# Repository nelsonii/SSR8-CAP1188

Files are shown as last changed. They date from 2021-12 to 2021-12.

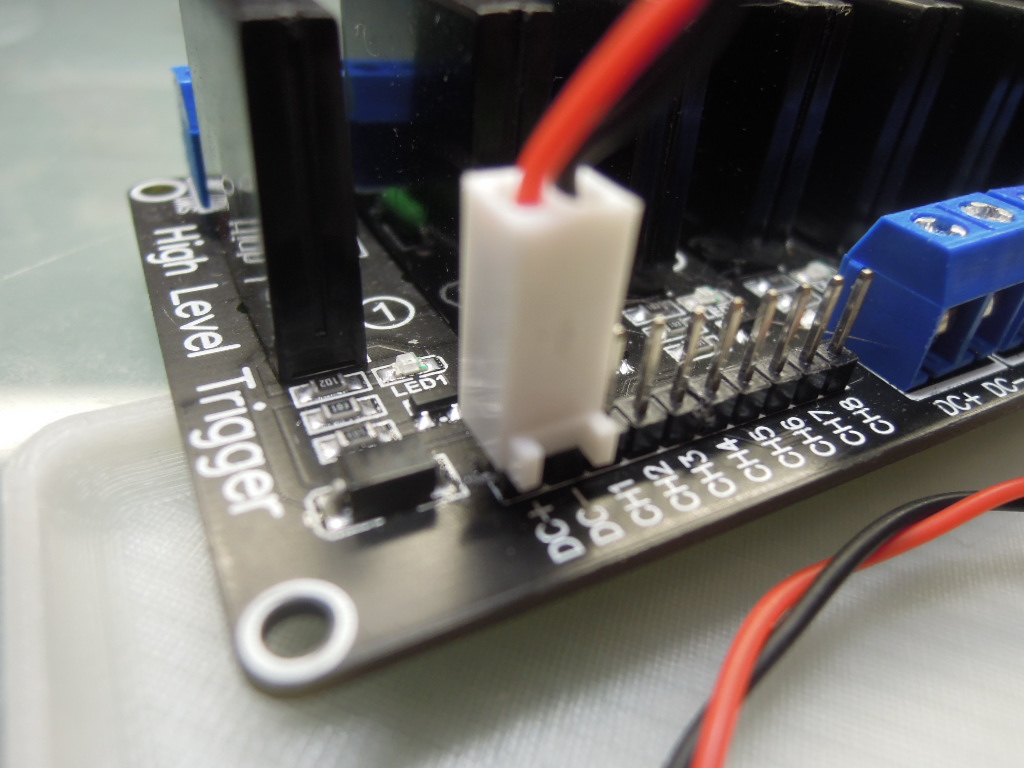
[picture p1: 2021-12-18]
2021-12-18/DSCN8659.JPG

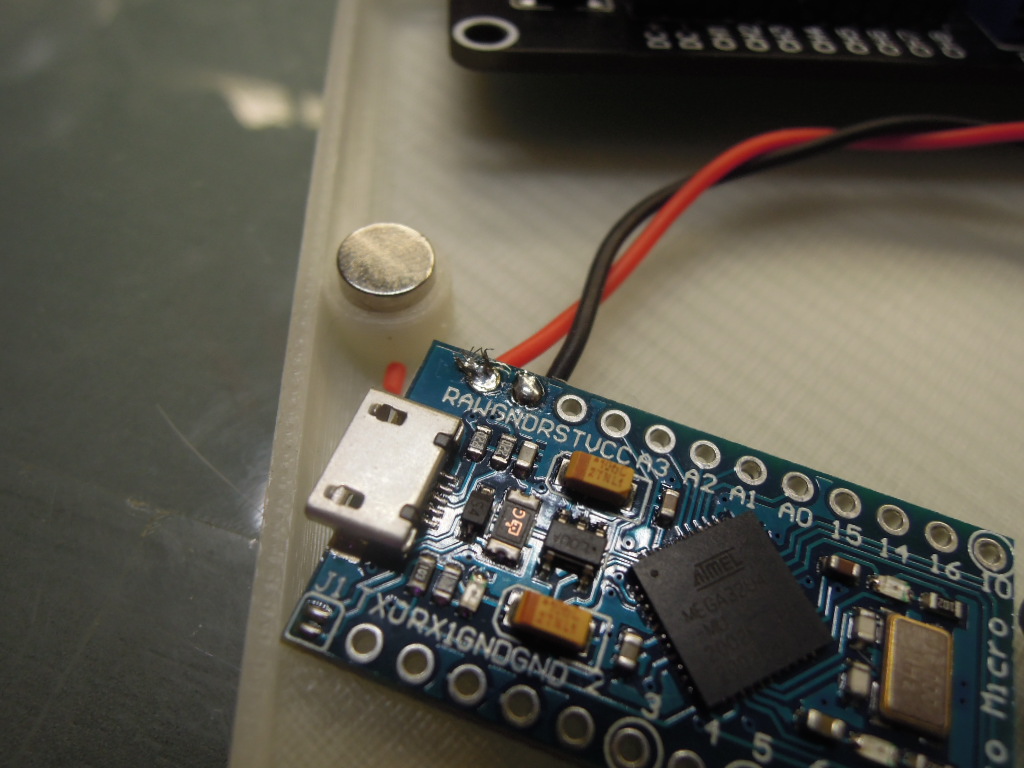
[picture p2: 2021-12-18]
2021-12-18/DSCN8655.JPG

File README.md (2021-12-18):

# SSR8-CAP1188
Controlling Solid Stay Relays with Capacitive Sensor (CAP1188) Board

BoM:

(1) AITRIP 2PCS 8 Channel 5V Solid State Relay Module Board High Level Trigger (or similar)
(1) Adafruit CAP1188 breakout board (or similar)
(1) USB To DIP Adapter 5pin Female Connector B Type PCB Converter (or similar -- or USB C, if you prefer)
(1) USB Type A Female Socket Breakout Board 2.54mm Pitch Adapter Connector DIP (optional -- for pass-thru power)
(1) Arduino Pro Mico or similar. Nano will work. Should also work with QT PY or similar.
(1) G/KF128 8 Pin 2.54mm Pitch PCB Screw Terminal Block Connector 150V 6A PCB Mount Screw Terminal Block Connector
(x) Assorted wire and connectors, solder, tools.

---

Power (VCC and GND) bussed through USB connectors, CAP, Arduino, and SSR -- common 5V power from USB in.
Power the device through the external supply connection, not the program port. (Prevents overload of Arduino.)

CAP1188 board LED outs go to SSR inputs.
CAP1188 board I2C to MCU.
CAP1188 board RST to MCU digital pin (any--define in code).

---

The two front-facing USB female connectors are for power in (from a wall wart) and power out (so you can daisy-chain).

I used a tiny (2.54mm pitch) screw terminal block for connecting the CAP inputs. You may choose a different connector.

Outbound connectors are already on the relay board.

---

If you print the enclosure, you can start (or only do) the bottom. That has all the mounting points. The top takes 2.5 hrs to print, so save that for when all is working. I'm using 6x2 magnets (4) to attach the top, as it will be removed often. 2.5x4mm screws for most boards, except 2.0mm for CAP1188. Invert the top Y 180 in slicer.

---

Caution: The relay board isn't always the greatest. I've found some of the screw terminal blocks to be broken, or messed up. You may need to re-solder them. Also, I found the Input Terminal blocks to be too big/sloppy for my wiring from the CAP1188. So, I used Molex connectors and the pin header found on the SSR board for the inputs. The extra benefit of this is that those blocks are free for other prototyping uses.

---

Some devices act a little weird on the output side. The little "singing baby shark" toy works perfectly. A cheap LED "snowglobe" can be intermittant. This may be a wiring problem in the device -- I'm still debugging.

---

You can use the default test code provided by Adafruit. You MUST add this line to setup: 
  //reverse led polarity
  //on-board led will go off, SSR will be triggered on
  cap.writeRegister(0x73, 0xFF);

---

WARNING: On startup, all outputs will go ACTIVE for a second, as the board boots. Do not use this in situations where this would cause a problem! I'm working on a better version which will "fail/start" off in all conditions. This will likely involve connecting the SSR directly to the Arduino Digital Outs, instead of piggy-backing on the CAP1188.

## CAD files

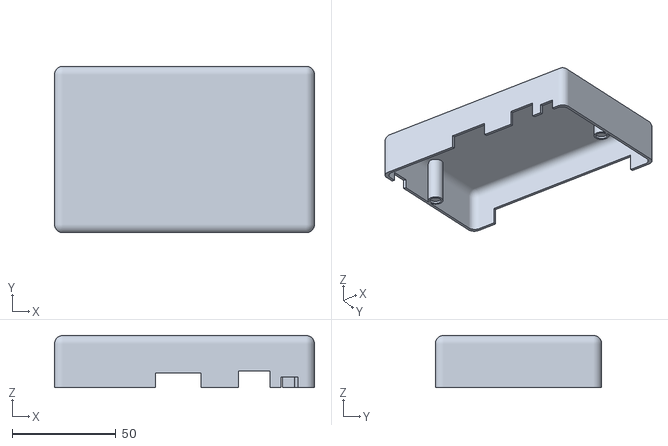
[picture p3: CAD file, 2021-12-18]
SSREnclosure/SSREnclosure_x8_v1L_TOP.stl
125.0 x 80.0 x 25.0

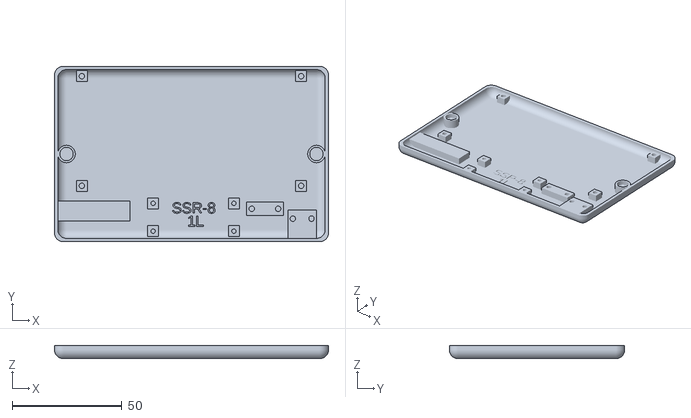
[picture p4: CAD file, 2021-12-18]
SSREnclosure/SSREnclosure_x8_v1L_BOT.stl
125.0 x 80.0 x 6.01

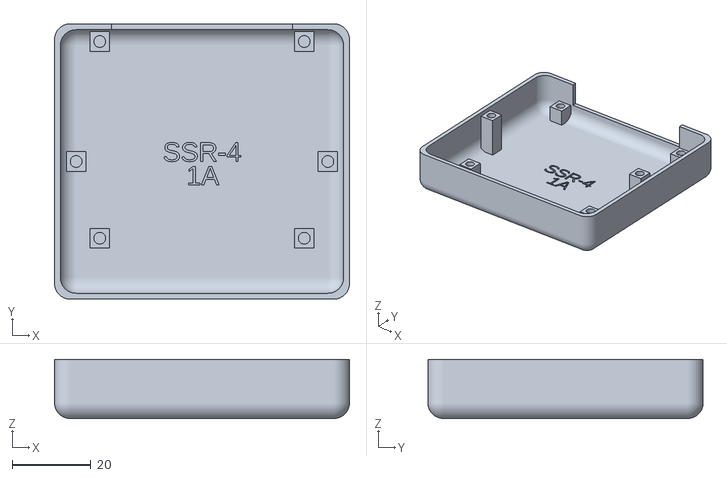
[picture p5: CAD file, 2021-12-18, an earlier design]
SSREnclosure/OLD/SSREnclosure_v1A.stl
75.0 x 70.0 x 15.0

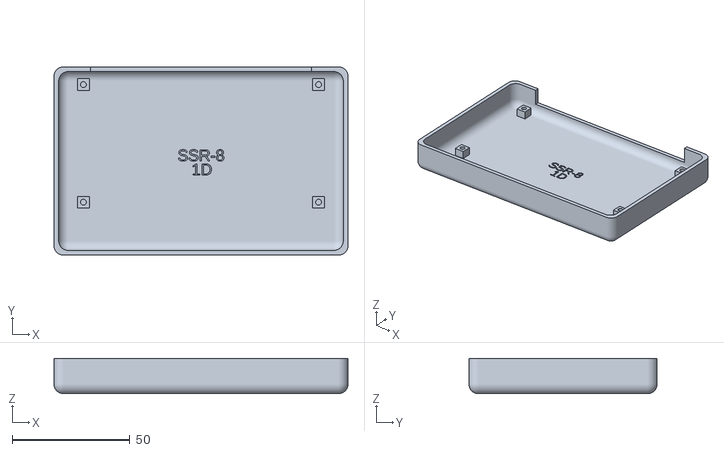
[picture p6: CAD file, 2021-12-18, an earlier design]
SSREnclosure/OLD/SSREnclosure_x8_v1D.stl
125.0 x 80.0 x 15.0

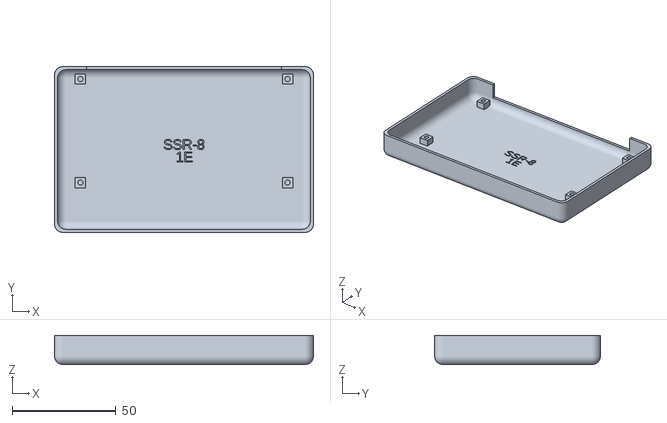
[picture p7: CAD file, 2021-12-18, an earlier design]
SSREnclosure/OLD/SSREnclosure_x8_v1E.stl
125.0 x 80.0 x 14.0

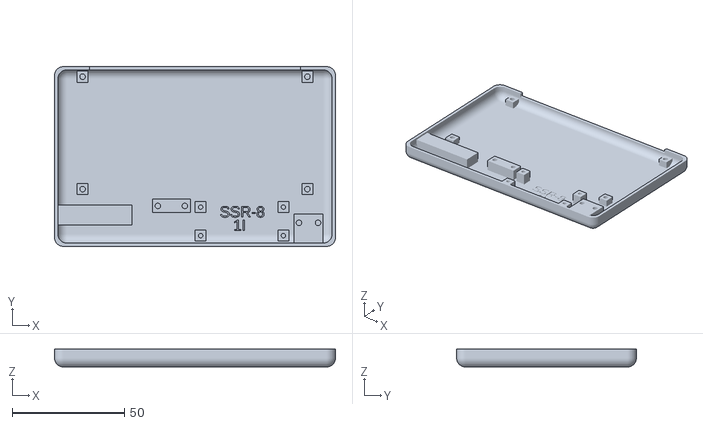
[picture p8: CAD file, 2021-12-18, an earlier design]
SSREnclosure/OLD/SSREnclosure_x8_v1I.stl
125.0 x 80.0 x 8.01

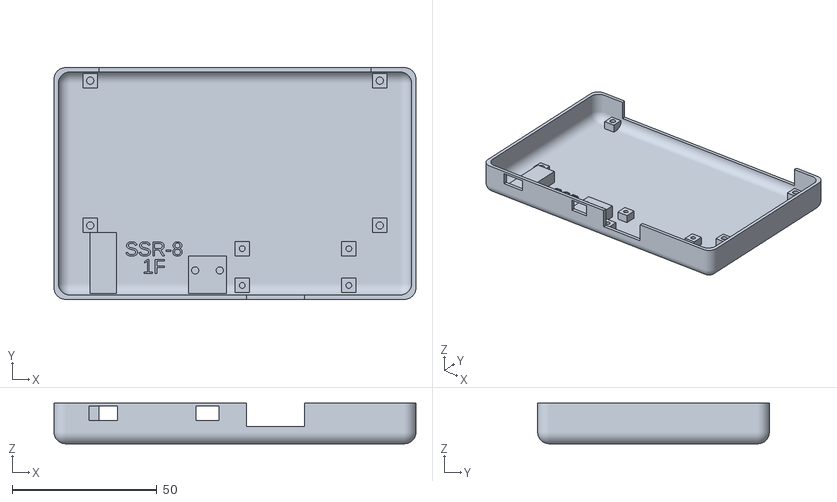
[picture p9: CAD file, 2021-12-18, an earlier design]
SSREnclosure/OLD/SSREnclosure_x8_v1F.stl
125.0 x 80.0 x 14.0

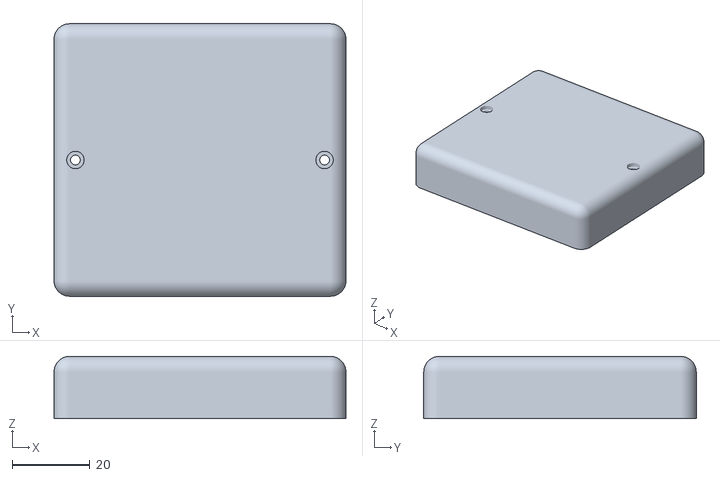
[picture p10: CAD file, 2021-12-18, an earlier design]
SSREnclosure/OLD/SSREnclosure_v1C_TOP.stl
75.0 x 70.0 x 16.0

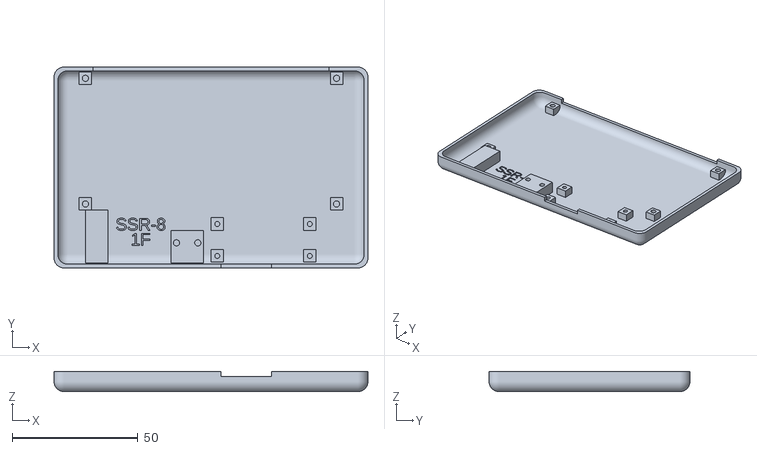
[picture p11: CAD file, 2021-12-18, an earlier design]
SSREnclosure/OLD/SSREnclosure_x8_v1F_BOT.stl
125.0 x 80.0 x 8.01

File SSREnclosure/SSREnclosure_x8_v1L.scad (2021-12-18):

fileDescription = "Solid State Relay Enclosure (x8)";
fileType = "SSR-8";
fileVersion = "1L";

// Designed to fit an 8 SSR board, QT PY 
// or Arduino Micro Pro (Leo) mcus
// and CAP1188 Capacitive sensor board.
// Includes breakout boards for USB Micro In and USB A Out

//The Belfry OpenSCAD Library
//https://github.com/revarbat/BOSL
include <BOSL/constants.scad>
use <BOSL/shapes.scad>

// using "high level trigger" so as to fail to "off"
// 8 solid state relay dimensions
// x=105, y=55, z=25
// z includes pins extending from PCB bottom
// mounting hole distance: x=100, y=50
// output jacks x=94, z=10

caseWidthX = 125;
caseDepthY = 80;
caseHeightZ = 32;
wallThickness = 3;

relayBoardMountX = 100;
relayBoardMountY = 50;
relayBoardOutputWidth = 94;

outputZ = 4; // height above Z-zero where connector is (works for both relay & cap board).

capBoardMountX = 36.83;
capBoardMountY = 12.7;
capBoardInputWidth = 22;
capBoardScrewDiameter = 2; //M2* for CAP1188 board

//This model supports two MCU board types. 
//QTPY = Adafruit QT PY board (USB-C)
//ARPO = Arduino Pro Micro (aka Leonardo)
//You can use other boards, but will need to do your own standoffs.
mcuType = "ARPO"; // either: QTPY or ARPO

mcuQtPyX = 21;
mcuQtPyY = 18;
mcuArPoX = 33;
mcuArPoY = 18;

standoffSize = 5; // size of standoffs/mounts for boards and case enclosure
overlap = 1; // overlap ensures that subtractions go beyond the edges


// M2.5*4 for relay board
// M2.5*4 for USB boards
// M2.0*  for CAP board -- requires M2.0 screws!
mountingScrewDiameter = 2.5; // M2.5
mountingScrewHeadDiameter = 4.5; // M2.5
mountingScrewHeadHeight = 2.7; // M2.5 

//case closure magnets (instead of screws)
magStandoffSize=8;
magDiameter=6.1;
magHeight=2.2;

emboss = true;
  
$fn=60; //circle smoothness
  
difference(){
  union() {
    difference(){
      //base
      //rounded cuboid is from the BOSL library
      //I'm using p1 setting to zero bottom (z). X/Y are centered on 0,0,0
      color("steelblue")
      cuboid([caseWidthX,caseDepthY,caseHeightZ], fillet=4, 
       p1=[-(caseWidthX/2), -(caseDepthY/2), 0]);
      //subtract out the inner cuboid
      cuboid([caseWidthX-wallThickness,caseDepthY-wallThickness,caseHeightZ-wallThickness], fillet=4, 
       p1=[-((caseWidthX-wallThickness)/2), -((caseDepthY-wallThickness)/2), (wallThickness/2)]);
      if (emboss) {
        //emboss version on inside case
        color("whitesmoke")
         translate([-9, -27, 1])
          linear_extrude(2)
           text(fileType, size=5);
        color("whitesmoke")
         translate([-2,-33, 1])
          linear_extrude(2)
           text(fileVersion, size=5);
      }//emboss
    }//difference (base)

    //relay board mounts
    color("khaki")
     translate([-(relayBoardMountX/2)-(standoffSize/2), (relayBoardMountY/2)+standoffSize+wallThickness, 1])
      cube([standoffSize,standoffSize,outputZ]);
    color("khaki")
     translate([+(relayBoardMountX/2)-(standoffSize/2), (relayBoardMountY/2)+standoffSize+wallThickness, 1])
      cube([standoffSize,standoffSize,outputZ]);
    color("khaki")
     translate([-(relayBoardMountX/2)-(standoffSize/2), -(relayBoardMountY/2)+standoffSize+wallThickness, 1])
      cube([standoffSize,standoffSize,outputZ]);
    color("khaki")
     translate([+(relayBoardMountX/2)-(standoffSize/2), -(relayBoardMountY/2)+standoffSize+wallThickness, 1])
      cube([standoffSize,standoffSize,outputZ]);
      
    //CAP1188 board mounts
    color("peachpuff")
     translate([-20+0, -30+standoffSize, 1])
      cube([standoffSize,standoffSize,outputZ]);
    color("peachpuff")
     translate([-20+capBoardMountX, -30+standoffSize, 1])
      cube([standoffSize,standoffSize,outputZ]);
    color("peachpuff")
     translate([-20+0, -30+standoffSize-capBoardMountY, 1])
      cube([standoffSize,standoffSize,outputZ]);
    color("peachpuff")
     translate([-20+capBoardMountX, -30+standoffSize-capBoardMountY, 1])
      cube([standoffSize,standoffSize,outputZ]);

    //Microcontroller board mount
    if (mcuType=="QTPY") {
      //MCU (ADAFRUIT QT PY) board mount
      color("hotpink")
       translate([-(caseWidthX/2)+(wallThickness/2), -(caseDepthY/2)+(wallThickness/2)+8, 1])
        cube([mcuQtPyX, mcuQtPyY/2, outputZ]);
    }
    if (mcuType=="ARPO") {
      //MCU (ARDUINO PRO MICRO) board mount
      color("deeppink")
       translate([-(caseWidthX/2)+(wallThickness/2), -(caseDepthY/2)+(wallThickness/2)+8, 1])
        cube([mcuArPoX, mcuArPoY/2, outputZ]);
    }
     
    //USB Micro breakout board mount (for power input)
    color("lime")
     translate([44, -(caseDepthY/2)+(wallThickness/2), 1])
      cube([13, 13, outputZ]);
      
    //Aux USB A output mount (for daisy chain of power to other devices)
    color("olive")
     translate([25, -28, 1])
      cube([17, 6, outputZ]);

    //case magnet mounts
    color("gold")
     translate([-57, 0, 1])
      cylinder(h=caseHeightZ-2, d=magStandoffSize);
    color("gold")
     translate([+57, 0, 1])
      cylinder(h=caseHeightZ-2, d=magStandoffSize);    
      
  }//union
  

  // Start of Difference stuff ************************************************************

  //Relay output connections
  color("coral")
   translate([-(relayBoardOutputWidth/2),(caseDepthY/2)-wallThickness, outputZ+2])
    cube([relayBoardOutputWidth, (wallThickness*2), 10]);

  //CAP input connections
  color("coral")
   translate([-20+6,-(caseDepthY/2)-wallThickness, outputZ+2])
    cube([capBoardInputWidth, (wallThickness*2), 8]);
  
  //MCU (PRG) connection (USB-C/Micro)
  color("coral")
   translate([-(caseWidthX/2)-(wallThickness/2), -(caseDepthY/2)+(wallThickness/2)+7.5, outputZ+2])
    cube([(wallThickness*2), 10, 6]);

  //Alt USB Micro power connection (in)
  color("coral")
     translate([46.50, -(caseDepthY/2)-wallThickness, outputZ+2])
      cube([8, (wallThickness*2), 6]);
    
  //Alt USA A power connection (out -- for daisy chain)
  color("coral")
     translate([26, -(caseDepthY/2)-wallThickness, outputZ+2])
      cube([15, (wallThickness*2), 9]);

  //screw holes for relay board mounts
  color("orangered")
   translate([-(relayBoardMountX/2), +(relayBoardMountY/2)+standoffSize+(standoffSize/2)+wallThickness, (wallThickness/2)])
    cylinder(h=outputZ, d=mountingScrewDiameter);
  color("orangered")
   translate([+(relayBoardMountX/2), +(relayBoardMountY/2)+standoffSize+(standoffSize/2)+wallThickness, (wallThickness/2)])
    cylinder(h=outputZ, d=mountingScrewDiameter); 
  color("orangered")
   translate([-(relayBoardMountX/2), -(relayBoardMountY/2)+standoffSize+(standoffSize/2)+wallThickness, (wallThickness/2)])
    cylinder(h=outputZ, d=mountingScrewDiameter);
  color("orangered")
   translate([+(relayBoardMountX/2), -(relayBoardMountY/2)+standoffSize+(standoffSize/2)+wallThickness, (wallThickness/2)])
    cylinder(h=outputZ, d=mountingScrewDiameter); 
    
  //screw holes for cap board mounts
  color("orangered")
   translate([-20+(standoffSize/2), -30+(standoffSize*1.5), (wallThickness/2)])
    cylinder(h=outputZ, d=capBoardScrewDiameter);
  color("orangered")
   translate([-20+(standoffSize/2)+capBoardMountX, -30+(standoffSize*1.5), (wallThickness/2)])
    cylinder(h=outputZ, d=capBoardScrewDiameter);
  color("orangered")
   translate([-20+(standoffSize/2), -30+(standoffSize*1.5)-capBoardMountY, (wallThickness/2)])
    cylinder(h=outputZ, d=capBoardScrewDiameter);
  color("orangered")
   translate([-20+(standoffSize/2)+capBoardMountX, -30+(standoffSize*1.5)-capBoardMountY, (wallThickness/2)])
    cylinder(h=outputZ, d=capBoardScrewDiameter);

  //screw holes for usb micro board mounts
  color("orangered")
   translate([46.25, -(caseDepthY/2)+(wallThickness/2)+9, (wallThickness/2)])
    cylinder(h=outputZ, d=mountingScrewDiameter);
  color("orangered")
   translate([54.75, -(caseDepthY/2)+(wallThickness/2)+9, (wallThickness/2)])
    cylinder(h=outputZ, d=mountingScrewDiameter);    

  //mounting screw holes for USB A pass-through (daisy chain power)
  color("orangered")
   translate([27.5, -(caseDepthY/2)+(wallThickness/2)+13.5, (wallThickness/2)])
    cylinder(h=outputZ, d=mountingScrewDiameter);
  color("orangered")
   translate([39.50, -(caseDepthY/2)+(wallThickness/2)+13.5, (wallThickness/2)])
    cylinder(h=outputZ, d=mountingScrewDiameter);    

  //magnet mounts for case
  color("tomato")
   translate([-57, 0, outputZ+2-magHeight])
    cylinder(h=magHeight*2, d=magDiameter);
  color("tomato")
   translate([+57, -0, outputZ+2-magHeight])
    cylinder(h=magHeight*2, d=magDiameter);

    
  //-------------------------------------------------------------------------------------------------------
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

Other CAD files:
SSREnclosure/OLD/SSREnclosure_v1C_BOT.stl
SSREnclosure/OLD/SSREnclosure_x8_v1K_TOP.stl
SSREnclosure/OLD/SSREnclosure_x8_v1G_BOT.stl
SSREnclosure/OLD/SSREnclosure_v1B_BOT.stl
SSREnclosure/OLD/SSREnclosure_x8_v1K_BOT.stl
SSREnclosure/OLD/SSREnclosure_x8_v1J.stl
SSREnclosure/OLD/SSREnclosure_v1A.scad
SSREnclosure/OLD/SSREnclosure_v1B.scad
SSREnclosure/OLD/SSREnclosure_v1C.scad
SSREnclosure/OLD/SSREnclosure_x8_v1C.scad
SSREnclosure/OLD/SSREnclosure_x8_v1D.scad
SSREnclosure/OLD/SSREnclosure_x8_v1E.scad
SSREnclosure/OLD/SSREnclosure_x8_v1F.scad
SSREnclosure/OLD/SSREnclosure_x8_v1G.scad
SSREnclosure/OLD/SSREnclosure_x8_v1H.scad
SSREnclosure/OLD/SSREnclosure_x8_v1I.scad
SSREnclosure/OLD/SSREnclosure_x8_v1J.scad
SSREnclosure/OLD/SSREnclosure_x8_v1K.scad

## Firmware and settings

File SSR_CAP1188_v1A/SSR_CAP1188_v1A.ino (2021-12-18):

/*************************************************** 
  This is a library for the CAP1188 I2C/SPI 8-chan Capacitive Sensor

  Designed specifically to work with the CAP1188 sensor from Adafruit
  ----> https://www.adafruit.com/products/1602

  These sensors use I2C/SPI to communicate, 2+ pins are required to  
  interface
  Adafruit invests time and resources providing this open source code, 
  please support Adafruit and open-source hardware by purchasing 
  products from Adafruit!

  Written by Limor Fried/Ladyada for Adafruit Industries.  
  BSD license, all text above must be included in any redistribution
 ****************************************************/
 
#include <Wire.h>
#include <Adafruit_CAP1188.h>

// Reset Pin
#define CAP1188_RESET  9


// For I2C, connect SDA to your Arduino's SDA pin, SCL to SCL pin
// On UNO/Duemilanove/etc, SDA == Analog 4, SCL == Analog 5
// On Leonardo/Micro, SDA == Digital 2, SCL == Digital 3
// On Mega/ADK/Due, SDA == Digital 20, SCL == Digital 21

// I2C, with reset pin
Adafruit_CAP1188 cap = Adafruit_CAP1188(CAP1188_RESET);


void setup() {

  Serial.begin(9600); delay(500);
  Serial.println("SSR CAP1188");

  // Initialize the sensor, if using i2c you can pass in the i2c address
  if (!cap.begin()) {
    Serial.println("CAP1188 not found");
    while (1);
  }
  Serial.println("CAP1188 found!");

  //reverse led polarity
  //on-board led will go off, SSR will be triggered on
  cap.writeRegister(0x73, 0xFF);
  
}//setup

void loop() {

  uint8_t touched = cap.touched();

  if (touched == 0) {
    // No touch detected
    return;
  }
  
  for (uint8_t i=0; i<8; i++) {
    if (touched & (1 << i)) { Serial.print("C"); Serial.print(i+1); Serial.print("  "); }
  }
  Serial.println();
  delay(50);
}//loop

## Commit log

2021-12-18 Arduino code
2021-12-18 OpenSCAD and STLs
    [SSREnclosure_v1A.scad, SSREnclosure_v1A.stl, SSREnclosure_v1B.scad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]
2021-12-18 Included assembly tips.
2021-12-18 Added note on printing.
2021-12-18 Detailed photos of assembly.
